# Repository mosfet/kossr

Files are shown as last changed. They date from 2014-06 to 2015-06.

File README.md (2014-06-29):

###KoSSR

A PWM controlled Solid State Relay. 8A at mains voltage, more with proper cooling, slightly based on the ACDimmer circuit by Robert Twomey (http://wiki.dxarts.washington.edu/groups/general/wiki/4dd69/AC_Dimmer_Circuit.html)

Originally designed to control a 120VAC 500W silicone heater mat for a 3d printer (http://github.com/mosfet/kossel-minimax)

The ATTiny45 reads an ADC pin sensing the PWM voltage from a control board, and a signal from the Zero-Cross sensing opto-isolator.

It uses these signals to control an opto-isolated triac (think mosfet for alternating current) in a controlled manner providing exact chopping of mains AC voltage.

Great for heating elements, dimming lightbulbs. More info can be found here: http://www.digikey.com/ca/en/techzone/lighting/resources/articles/Retrofit-LED-Bulbs-and-Drivers.html

**Basic BOM:**

Mouser Shopping Cart:

https://www.mouser.com/ProjectManager/ProjectDetail.aspx?AccessID=5bcadebf04

$6.39 for all parts except circuit board

*TODO:*

Add firmware support for 50hz and AREF comparison (rather than internal aref)

Hardware rc filter for PWM smoothing?

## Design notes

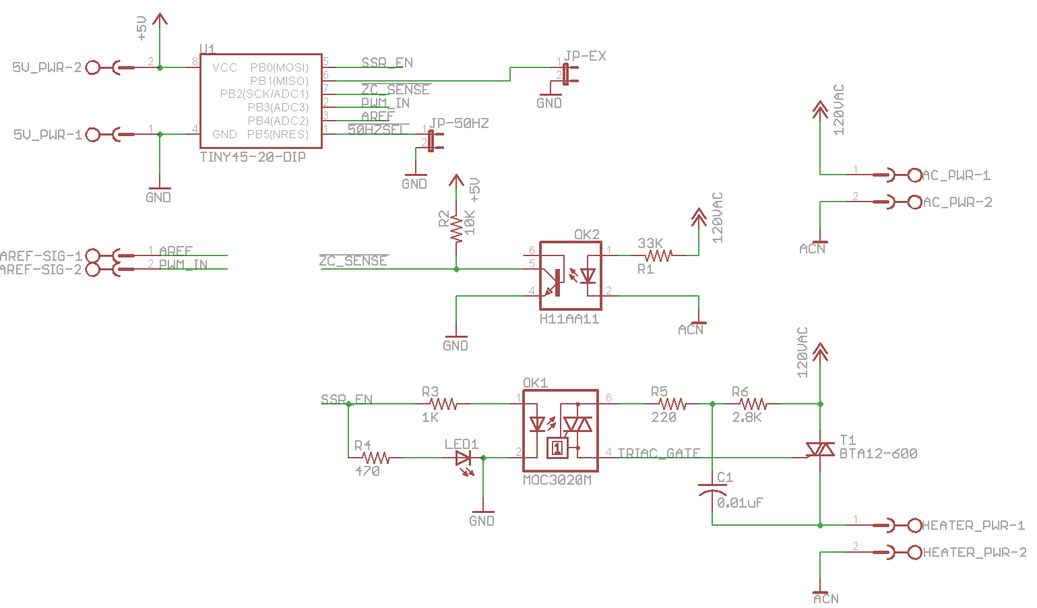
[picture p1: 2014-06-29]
pictures/schematic.png

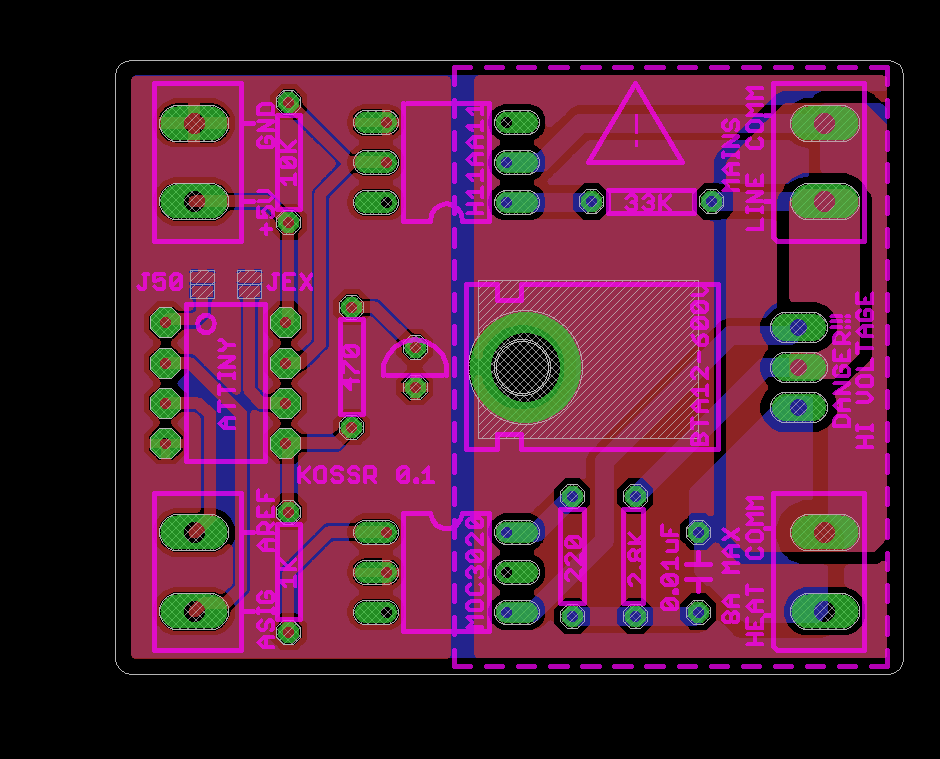
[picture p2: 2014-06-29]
pictures/board.png

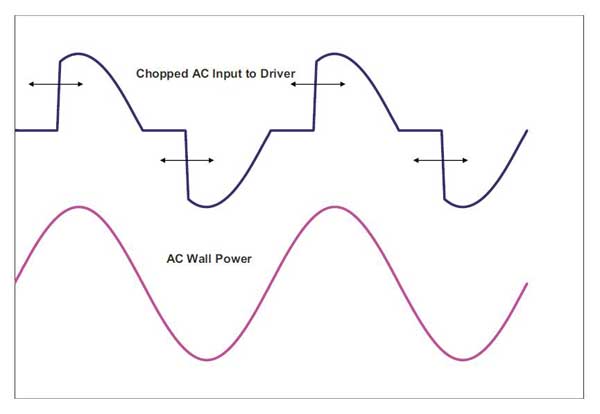
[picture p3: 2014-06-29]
pictures/chopping-ac.jpg

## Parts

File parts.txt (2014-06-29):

Mouser Shopping Cart:
https://www.mouser.com/ProjectManager/ProjectDetail.aspx?AccessID=5bcadebf04
$6.39 for all parts except circuit board

Partlist

Exported from kossr.sch at 6/28/2014 7:56:33 PM

EAGLE Version 6.3.0 Copyright (c) 1988-2012 CadSoft

Assembly variant: 

Part       Value          Device                Package      Library            Sheet

5V_PWR                    MSTBV2                MSTBV2       con-phoenix-500    1
AC_PWR                    MSTBV2                MSTBV2       con-phoenix-500    1
AREF-SIG                  MSTBV2                MSTBV2       con-phoenix-500    1
C1         0.01uF         C-US050-024X044       C050-024X044 adafruit           1
HEATER_PWR                MSTBV2                MSTBV2       con-phoenix-500    1
JP-50HZ                   JUMPER-2SMD-NO        SJ_2S-NO     SparkFun-Retired   1
JP-EX                     JUMPER-2SMD-NO        SJ_2S-NO     SparkFun-Retired   1
LED1                      LED3MM                LED3MM       led                1
OK1        MOC3020M       MOC3020M              DIL06        optocoupler        1
OK2        H11AA11        H11AA11               DIL06        twomey             1
R1         33K            R-US_0207/7           0207/7       rcl                1
R2         10K            R-US_0207/7           0207/7       rcl                1
R3         1K             R-US_0207/7           0207/7       rcl                1
R4         470            R-US_0207/7           0207/7       rcl                1
R5         220            R-US_0207/7           0207/7       rcl                1
R6         2.8K           R-US_0207/7           0207/7       rcl                1
T1         BTA12-600      BTA12-600             TO220AB      twomey             1
U1         TINY45-20-DIP  ATTINY45TINY45-20-DIP DIP08        SparkFun-DigitalIC 1

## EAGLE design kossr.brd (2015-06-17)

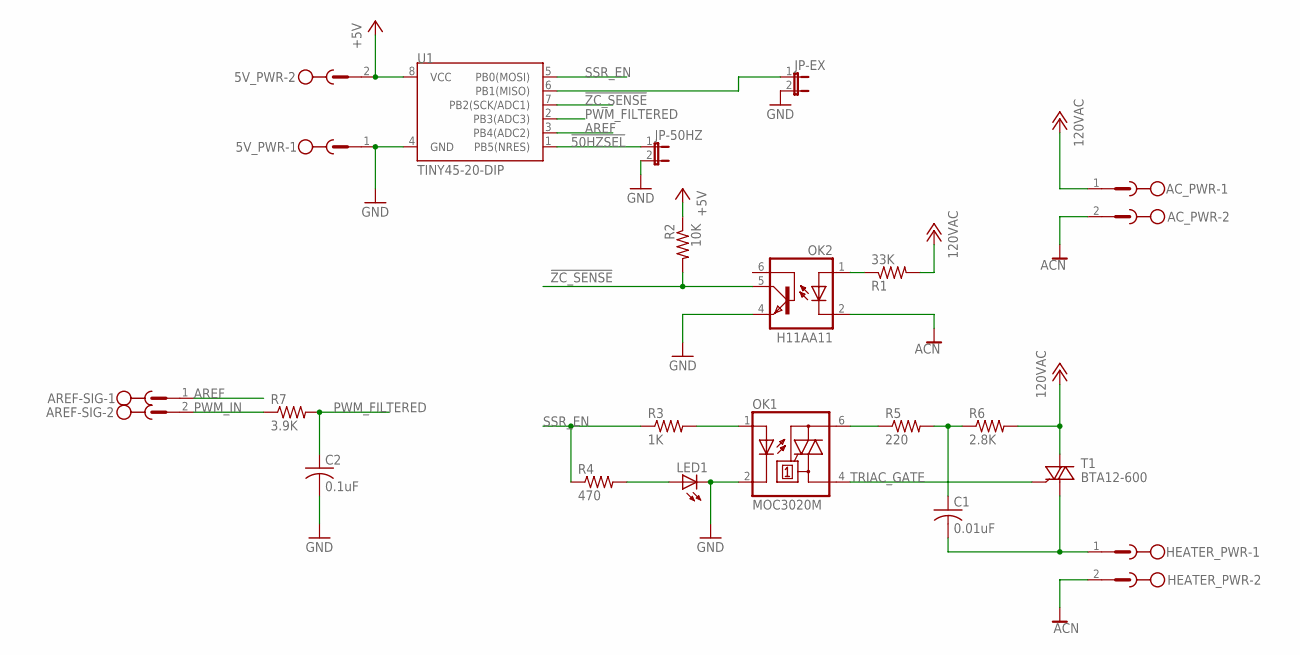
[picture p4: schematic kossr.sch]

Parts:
5V_PWR: MSTBV2
AC_PWR: MSTBV2
AREF-SIG: MSTBV2
C1: 0.01uF; C050-024X044
C2: 0.1uF; C025-024X044
HEATER_PWR: MSTBV2
JP-50HZ: JUMPER-2SMD-NO; SJ_2S-NO
JP-EX: JUMPER-2SMD-NO; SJ_2S-NO
LED1: LED3MM
OK1: MOC3020M; DIL06
OK2: H11AA11; DIL06
R1: 33K; 0207/7
R2: 10K; 0207/7
R3: 1K; 0207/7
R4: 470; 0207/7
R5: 220; 0207/7
R6: 2.8K; 0207/7
R7: 3.9K; 0207/7
T1: BTA12-600; TO220AB
U1: TINY45-20-DIP; DIP08

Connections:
!50HZSEL: JP-50HZ.1, U1.1 (PB5(NRES))
!EX: JP-EX.1, U1.6 (PB1(MISO))
!ZC_SENSE: OK2.5 (COL), R2.2, U1.7 (PB2(SCK/ADC1))
+5V: 5V_PWR.2, R2.1, U1.8 (VCC)
ACHOT: AC_PWR.1, R1.2, R6.2, T1.2 (A2)
ACN: AC_PWR.2, HEATER_PWR.2, OK2.2 (C)
AREF: AREF-SIG.1, U1.3 (PB4(ADC2))
GND: 5V_PWR.1, C2.2, JP-50HZ.2, JP-EX.2, LED1.K (C), OK1.2 (C), OK2.4 (EMI), U1.4 (GND)
HEATERHOT: C1.2, HEATER_PWR.1, T1.1 (A1)
unnamed: OK2.1 (A), R1.1
unnamed: LED1.A, R4.2
unnamed: OK1.1 (A), R3.2
unnamed: C1.1, R5.2, R6.1
unnamed: OK1.6 (A2), R5.1
PWM_FILTERED: C2.1, R7.2, U1.2 (PB3(ADC3))
PWM_IN: AREF-SIG.2, R7.1
SSR_EN: R3.1, R4.1, U1.5 (PB0(MOSI))
TRIAC_GATE: OK1.4 (A1), T1.3 (G)

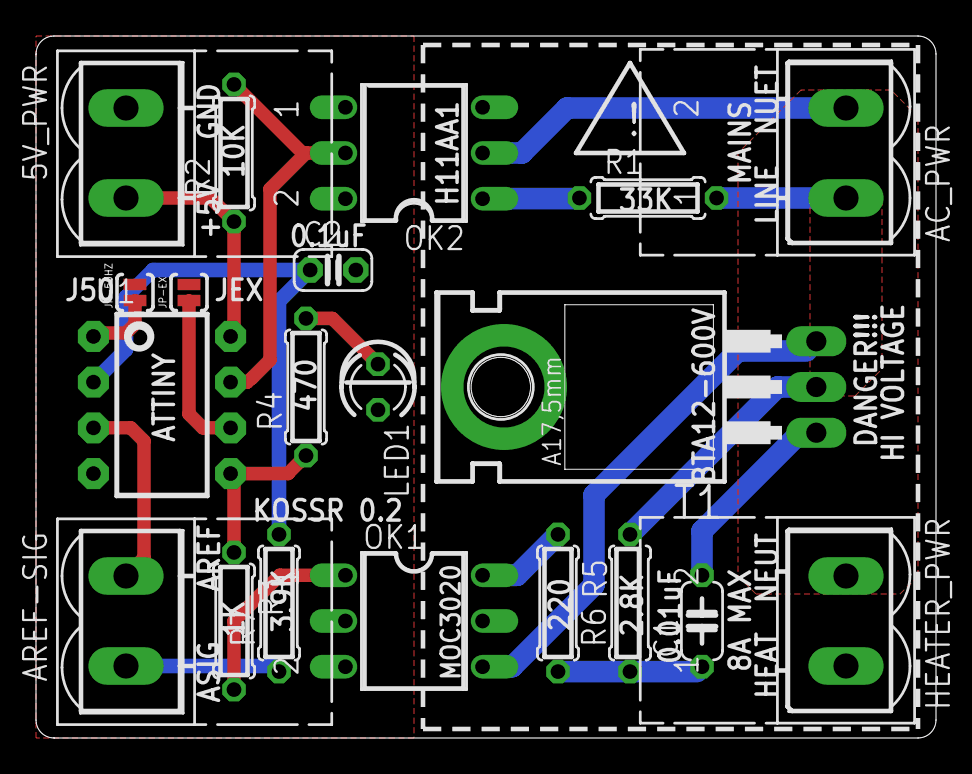
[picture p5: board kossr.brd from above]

Board: 2 copper layers, 50.0 x 39.0 mm, 20 parts (0 on the bottom side), 18 nets.

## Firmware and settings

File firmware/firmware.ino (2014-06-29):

//pins
#define PIN_ZC_SENSE 2
#define PIN_SSR_ENABLE 0
#define PIN_PWM_IN 3

//zero cross sensing... this works for 60hz
#define MAX_DELAY 7300     //max delay possible before voltage disappears
#define OFF_THRESHOLD 7200 //dimmest before turning it completely off
#define ON_THRESHOLD 1100 //lightest before turning it completely on
#define MIN_DELAY 1000     //min delay possible before output equals input
#define ULONG_MAX 4294967295
volatile unsigned long turnOnAt = ULONG_MAX;  
int currentDelay = MIN_DELAY;

//averaging variables
#define SAMPLECOUNT 16
int readings[SAMPLECOUNT];      // the readings from the analog input
int index = 0;                  // the index of the current reading
int total = 0;                  // the running total
int avg = 0;

void setup(){
 pinMode(PIN_SSR_ENABLE, OUTPUT);
 pinMode(PIN_ZC_SENSE, INPUT);
 attachInterrupt(0,zc,RISING); 
 digitalWrite(PIN_SSR_ENABLE, LOW);
}

void loop(){
  if(micros() >= turnOnAt){
    if(currentDelay < OFF_THRESHOLD) //if lower than the off threshhold, don't bother turning it on
      digitalWrite(PIN_SSR_ENABLE, HIGH);

    delayMicroseconds(50);
    if(currentDelay > ON_THRESHOLD) //if higher than the on threshold, don't bother turning it off
      digitalWrite(PIN_SSR_ENABLE, LOW);
    turnOnAt = ULONG_MAX;
  }
  else
  {
    total-= readings[index]; 
    readings[index] = analogRead(PIN_PWM_IN);     
  
    total+=readings[index];          
    index++;                        
  
    if (index >= SAMPLECOUNT)              
      index = 0;                          

    currentDelay = map(total/SAMPLECOUNT, 0, 1023, MAX_DELAY, MIN_DELAY);
    delayMicroseconds(750);
  }
}

void zc(){
  turnOnAt = micros() + currentDelay; //currentDelay;
}

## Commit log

2014-06-29 kossr Initial Checkin
    [kossr.brd, kossr.sch, kossr2.sch]
2014-06-29 Add parts and images
    [kossr2.sch]
2015-06-17 update to kossr 0.2
    adds input r/c filter
    [kossr.brd, kossr.sch]

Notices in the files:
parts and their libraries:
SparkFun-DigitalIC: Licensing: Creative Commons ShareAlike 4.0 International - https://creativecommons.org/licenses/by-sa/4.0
